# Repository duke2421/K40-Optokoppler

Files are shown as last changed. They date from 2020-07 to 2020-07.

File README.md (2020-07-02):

# K40-Optokoppler
Platine mit Optokoppler um das K40-Netzteil mit PWM anzusteuern

Erstellt mit KiCad

Mit dieser Platine kann der L Anschluss vom K40 Netzteil (MYJG 40W) mit PWM angesteuert werden. 

Mein K40 wird mit dem MPCNC-Nano-Estlcam-Shield angesteuert. An diese Optokoppler-Platine kann der Spindelausgang, bzw. die PWM vom Arduino Nano angeschlossen werden, der Stecker vom K40 Netzteil wird dann einfach an diese Platine gesteckt, keine weiteren Änderungen an der Verkabelung vom Netzteil notwendig. Die 24V für die Schrittmotoren und die Steuerung selber wird durch ein zusätzliches Netzteil zur Verfügung gestellt, wobei auch die 24V aus dem Lasernetzteil gehen sollten, das habe ich aber nicht getestet.

Im Ordner "Halter" ist noch ein kleines STL, bzw. FreeCAD-File für einen Abstandhalter. Damit kann die Platine ans Blech des K40 isoliert angeschraubt werden.

Verwendung auf eigene Gefahr, wenn nach Einbau dieser Platine euer K40 nicht mehr funktioniert, seid Ihr selbst schuld, nicht ich ;)

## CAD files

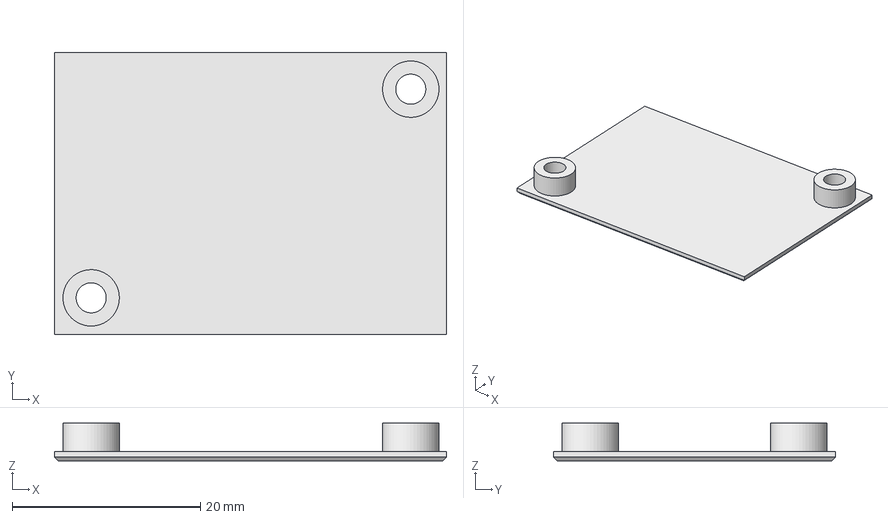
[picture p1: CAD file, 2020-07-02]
Halter/Abstandshalter.FCStd
41.7 x 30.0 x 4.00 mm

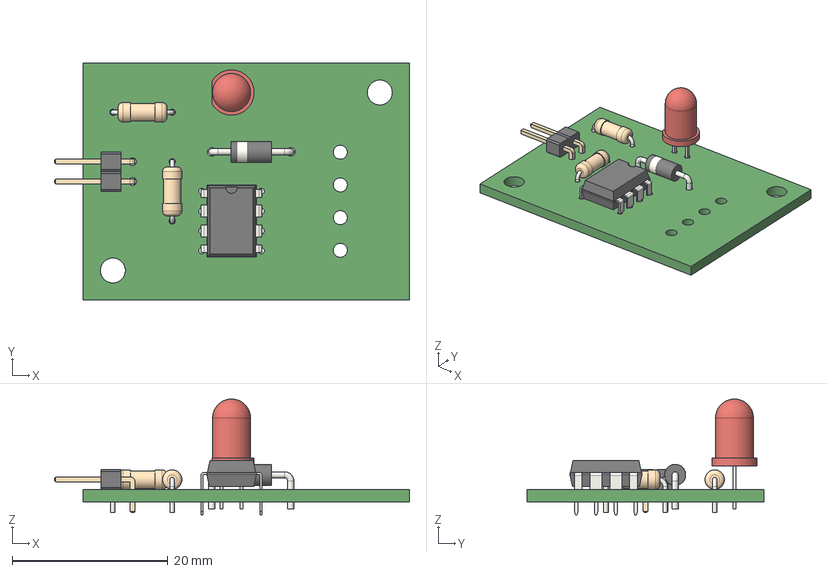
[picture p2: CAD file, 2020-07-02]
K40Optokoppler.step
45.6 x 30.5 x 14.9 mm

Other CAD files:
Halter/Abstandshalter.stl

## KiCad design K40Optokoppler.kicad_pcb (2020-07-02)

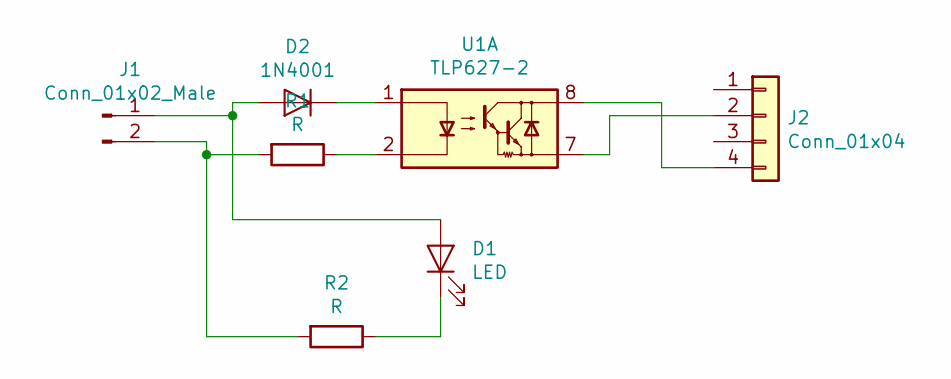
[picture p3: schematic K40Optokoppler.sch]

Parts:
D1: LED; LED_D5.0mm
D2: 1N4001; D_DO-41_SOD81_P10.16mm_Horizontal
J1: Conn_01x02_Male; PinHeader_1x02_P2.54mm_Horizontal
J2: Conn_01x04; JST-4.2mm_1x4
R1, R2: R; R_Axial_DIN0207_L6.3mm_D2.5mm_P7.62mm_Horizontal
U1: TLP627-2; DIP-8_W7.62mm

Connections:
unnamed: D1.1 (K), R2.1
unnamed: D1.2 (A), D2.2 (A), J1.1
unnamed: D2.1 (K), U1.1
unnamed: J1.2, R1.2, R2.2
unnamed: J2.2, U1.7
unnamed: J2.4, U1.8
unnamed: R1.1, U1.2

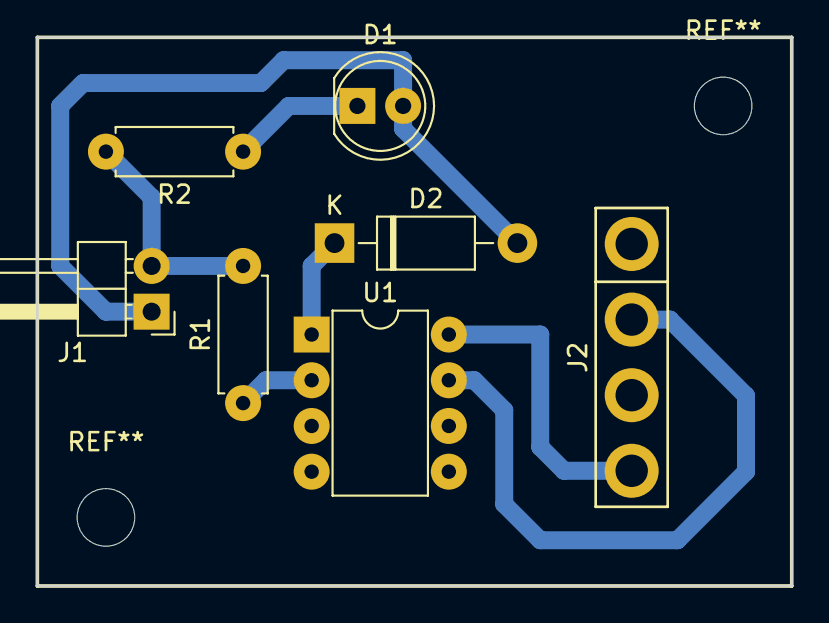
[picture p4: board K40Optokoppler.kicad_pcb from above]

Board: 2 copper layers, 41.9 x 30.5 mm, 7 parts (0 on the bottom side), 7 nets.

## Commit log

2020-07-02 Erstes Release
    [Abstandshalter.FCStd, Abstandshalter.stl, K40Optokoppler.kicad_pcb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]
2020-07-02 Step-Datei
    Step-Datei der Platine hinzugefügt
    [K40Optokoppler.kicad_pcb, K40Optokoppler.step]
